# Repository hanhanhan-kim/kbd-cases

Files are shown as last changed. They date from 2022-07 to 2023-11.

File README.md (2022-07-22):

# Keyboard Cases

A collection of keyboard cases I've designed. For each keyboard case, I provide all files for assembly, as well as instructions for setting up the case. Most of my cases target 40% ortholinear keyboards. 

| Case | Mounting Style | Target Keyboard | Photo |
| --- | --- | --- | --- |
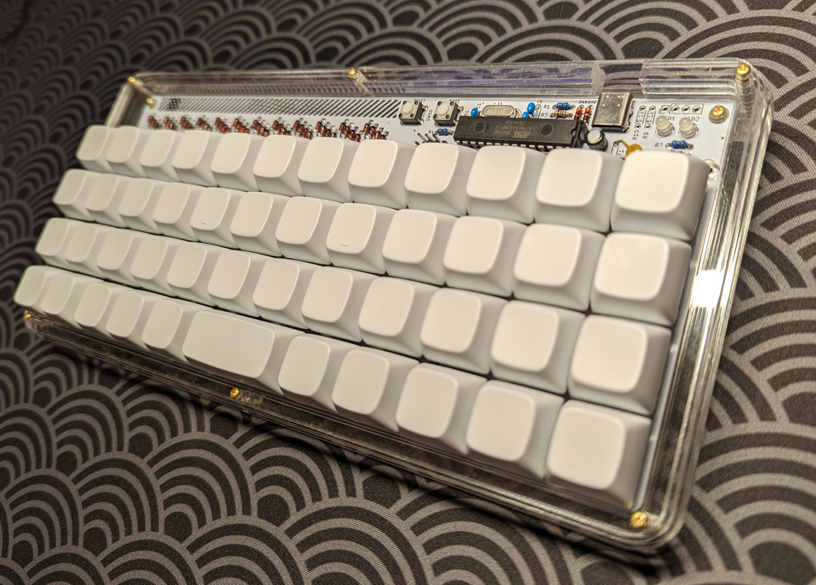
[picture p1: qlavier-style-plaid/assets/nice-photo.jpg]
| [Qlavier](./qlavier-style-plaid) | Silicone o-ring burger mount | [Plaid](https://github.com/hsgw/plaid) |  |
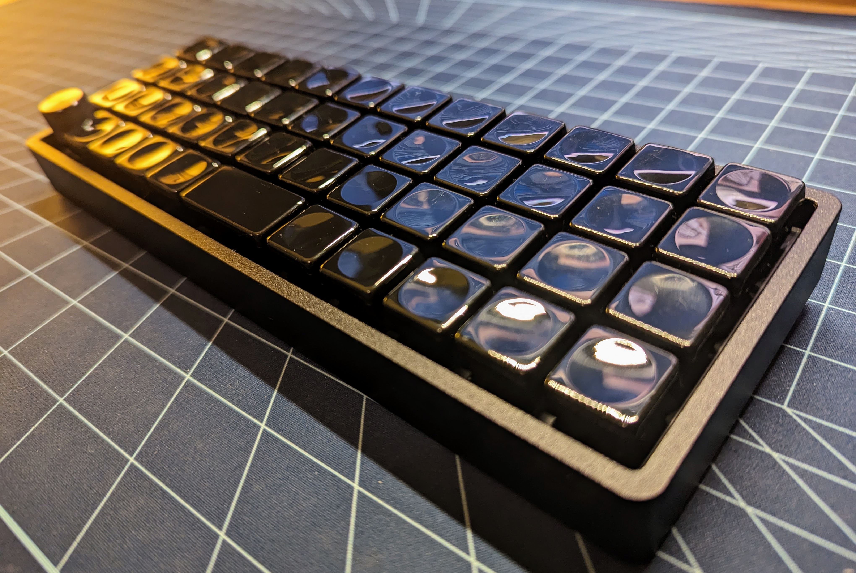
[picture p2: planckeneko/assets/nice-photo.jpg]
| [Planckeneko](./planckeneko) | Gummy o-ring gasket mount | [Planck](https://olkb.com/) |  |

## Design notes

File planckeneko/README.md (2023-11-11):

# Planckeneko

*A gummy o-ring gasket-mounted case for the popular [Planck](https://olkb.com/collections/planck) keyboard. Based on the cleverly designed [Bakeneko 60](https://github.com/kkatano/bakeneko-60).*



This project provides hardware files and assembly instructions for building a CNC-machined brass-weighted gasket-mounted case for the [Planck](https://olkb.com/collections/planck) keyboard. Alternative hardware files are provided for CNC-machining a version of the case without the brass weight, but explicit instructions are not provided (assembly can be figured out from the instructions for the brass-weighted version). This project also provides hardware files for making a 3D-printed version of the case, and again, explicit assembly instructions are not provided, because the assembly can be inferred from the instructions for the brass-weighted version here. 

## BOM

Aside from the CNC-machined (or 3D-printed) parts*, the following items are needed for the case:

| Item | Unit Price (USD) | Quantity | Source |
| --- | --- | --- | --- |
| Soft silicone o-ring, 1/8" fractional width, 70 Duro hardness| 10.18 | 1 | O-Ring Store [B70260](https://www.theoringstore.com/store/index.php?main_page=product_info&cPath=367_23_25&products_id=1275) |
| Unified daughterboard, 4-pin JST cable, four M2 x4 mm screws | 8.00 | 1 | Cannon Keys [UNIFIED-DB](https://cannonkeys.com/products/unified-daughterboard-and-jst-cable) ** |
| M2 x4 mm brass hex drive flat head screw | 7.33 / n | 2 | McMaster [97595A266](https://www.mcmaster.com/97595A266/) |
| Wide furniture bumpers | 6.98 / 4 | 4 | ASIN [B0856T8HJF](https://www.amazon.com/gp/product/B0856T8HJF/ref=ppx_yo_dt_b_search_asin_title?ie=UTF8&psc=1) |

*If 3D-printing, use the files found [here](./3dp). If CNC-machining with no brass bar, use the files found [here](./cnc-plain). If CNC-machining with the weighted brass bar, use the files found [here](./cnc-weighted). 

**The daughterboard is [open-sourced](https://github.com/ai03-2725/Unified-Daughterboard), so it can be manufactured for cheaper, but in multiples, at a PCB fabrication house. 

## Assembly

The [drawing](./assets/drawing.png) gives us a reasonable idea of the case geometry. Note the recesses on the bottom:

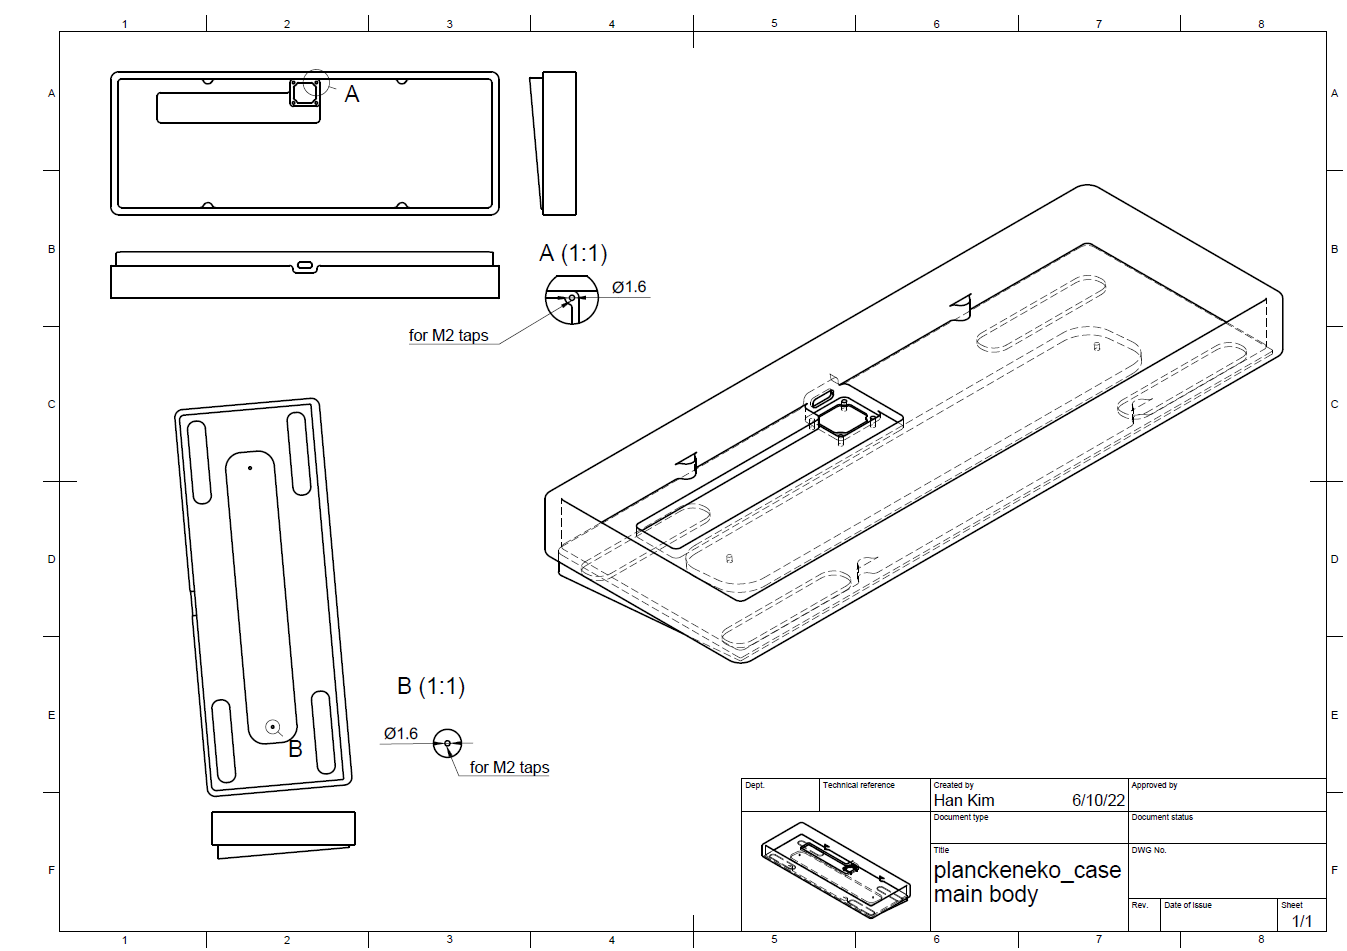
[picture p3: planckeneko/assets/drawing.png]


Lay out the CNC'd parts.



Use the flat head M2 screws to screw the brass bar into the bottom recess of the main case body. Carefully stick on the furniture bumpers into their dedicated recesses. 

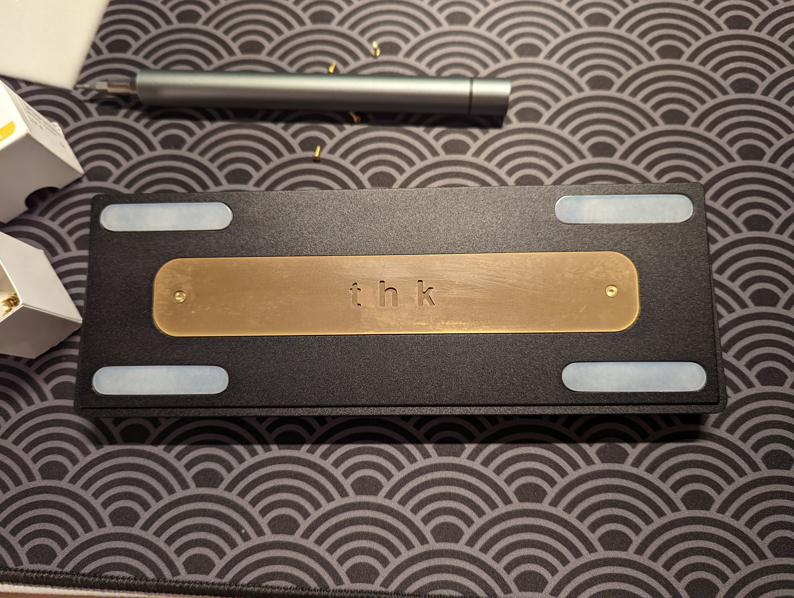
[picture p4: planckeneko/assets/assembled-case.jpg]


We now need to modify the Planck PCB. We need to desolder the original USB-C port off the Planck. Then, we need to cut out the jutted part of the PCB that supported the original USB-C port. I found that a pair of flush-cutters did the trick just fine. The image below marks in red what the PCB looks like after the protrusion's been cut:

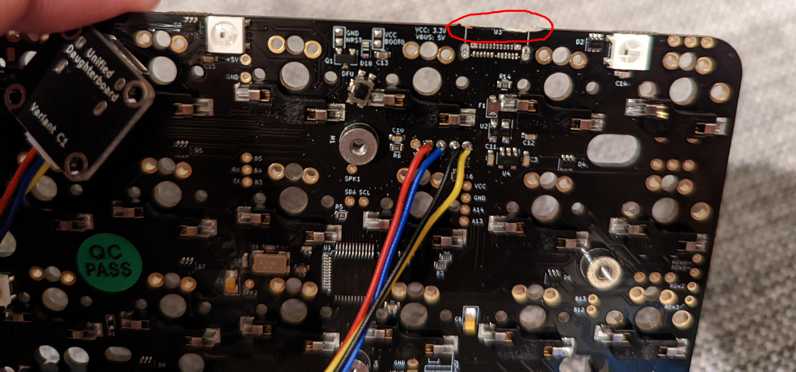
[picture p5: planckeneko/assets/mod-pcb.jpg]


Notice that the above image also has some red, blue, black, and yellow wires soldered in. These wires are the JST cable wires that go into the USB-C daughterboard. The Planck PCB has a neat feature, where we can bypass the original USB port, and install our own upstream. This feature is handy in the case of defective USB ports, but it's also handy because it lets us install a daughterboard, which is expected of mostf gasket-mounted keyboards.  Unfortunately, the daughterboard JST wires that come from Cannon Keys are not the standard colours for USB 2.0, so we should look at the [daughterboard's datasheet](https://github.com/ai03-2725/Unified-Daughterboard/wiki/PCB-side-design-resources) (doing so is always good practice, anyway). Here, we can see the USB pinout for the daughterboard:

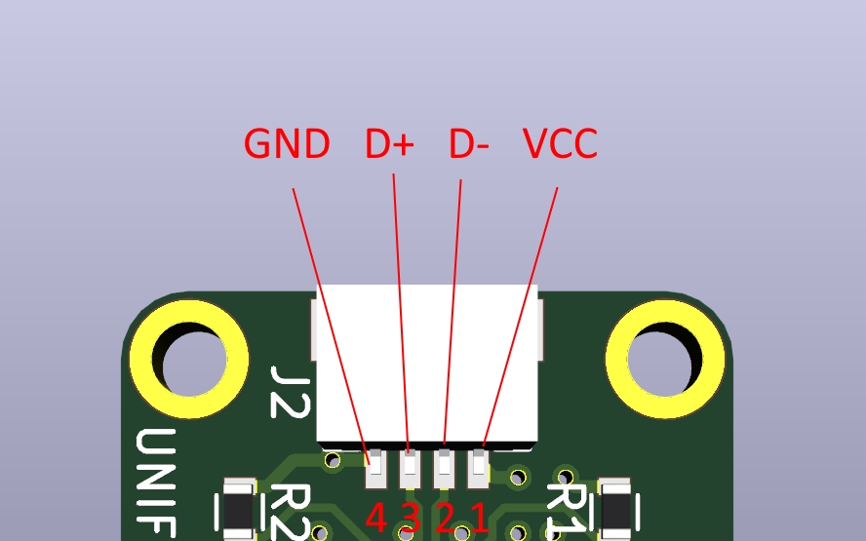
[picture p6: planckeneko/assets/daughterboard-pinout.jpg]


Similarly, we can see the USB pinout silkscreened on the breakout holes of the Planck PCB:

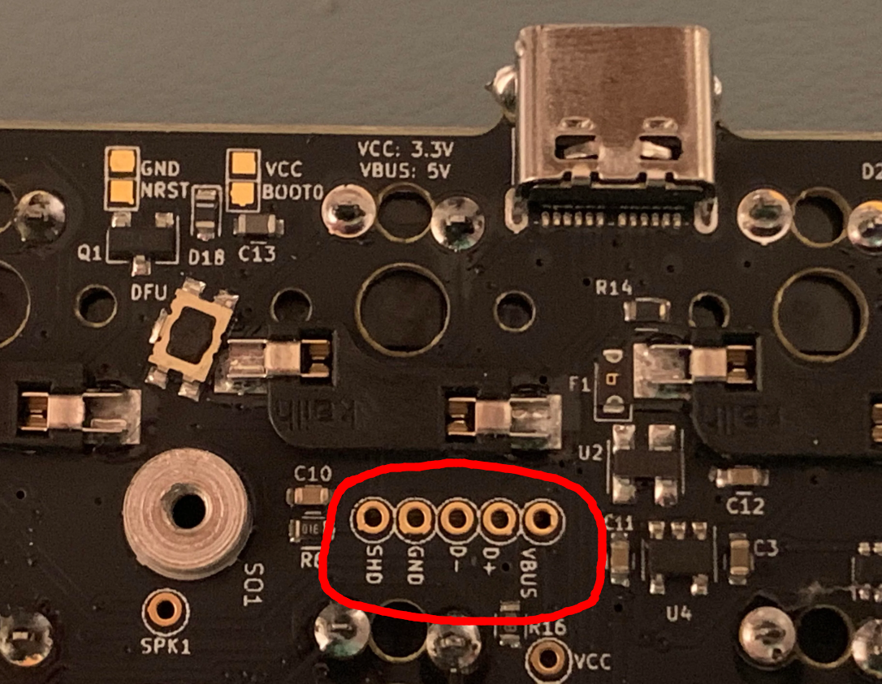
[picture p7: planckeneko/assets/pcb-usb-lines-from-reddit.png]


We can ignore the SHD pin, and connect the USB pins on the Planck PCB to the corresponding USB daughterboard PCB pins. The Planck PCB clearly doesn't have a JST connector though, so we're going to cut off the JST connector on one end of the cable, and solder the wires directly to the Planck (as shown a few images above, with the red, blue, black, and yellow wires). The daughterboard has JST connectors though, so we can just click those in place. Remember to solder the JST wires to the _bottom_ side of the Planck PCB. Once all the electrical connections are complete, screw the daughterboard into the case. We should now have something that looks like this:

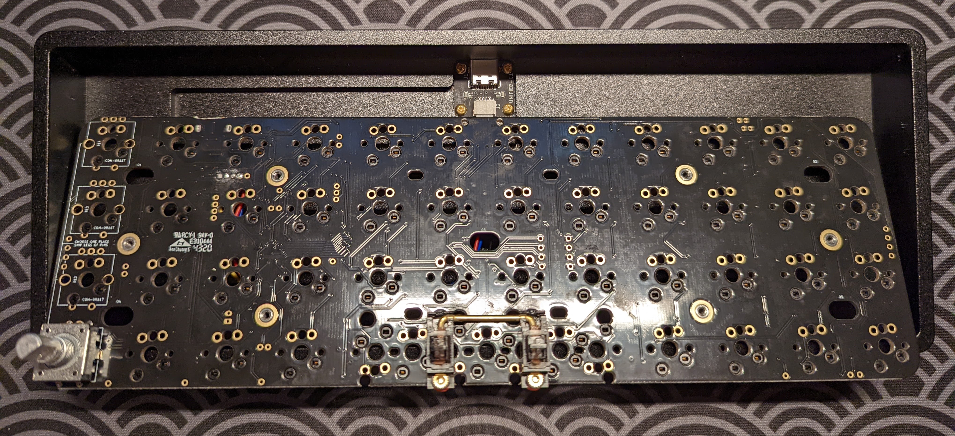
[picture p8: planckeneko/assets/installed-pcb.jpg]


We now install the switches and switch plate, just like a normal keyboard build. Then, we wrap the o-ring around the entire PCB / switch plate, such that the o-ring sits happily between PCB and the switch plate. Set this construction into the keyboard case, with the south side facing first. The o-ring on the south side of the PCB construction should sit nicely on the semi-circular columns found on the inside edge of the case.

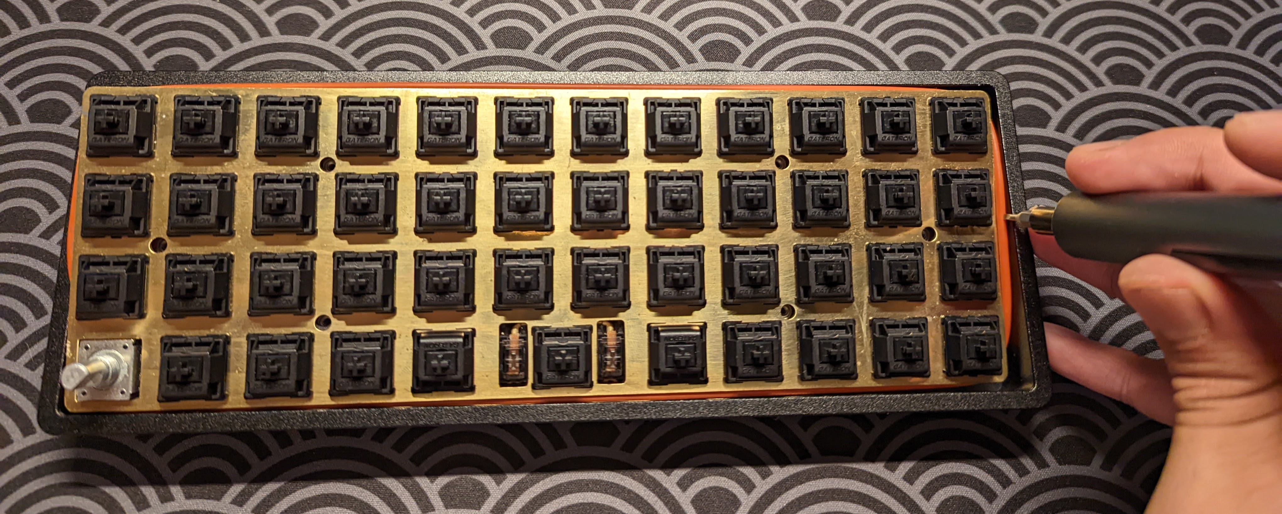
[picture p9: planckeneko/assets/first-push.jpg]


Use a flathead screwdriver to push down the o-ring and the PCB assembly, all around the assembly's edges. Eventually, the o-ring should be reasonably hidden (but admittedly, not completely, depending on your view angle). The o-ring I've since opted for using is black (from the O-Ring Store) rather than black (from McMaster-Carr). 

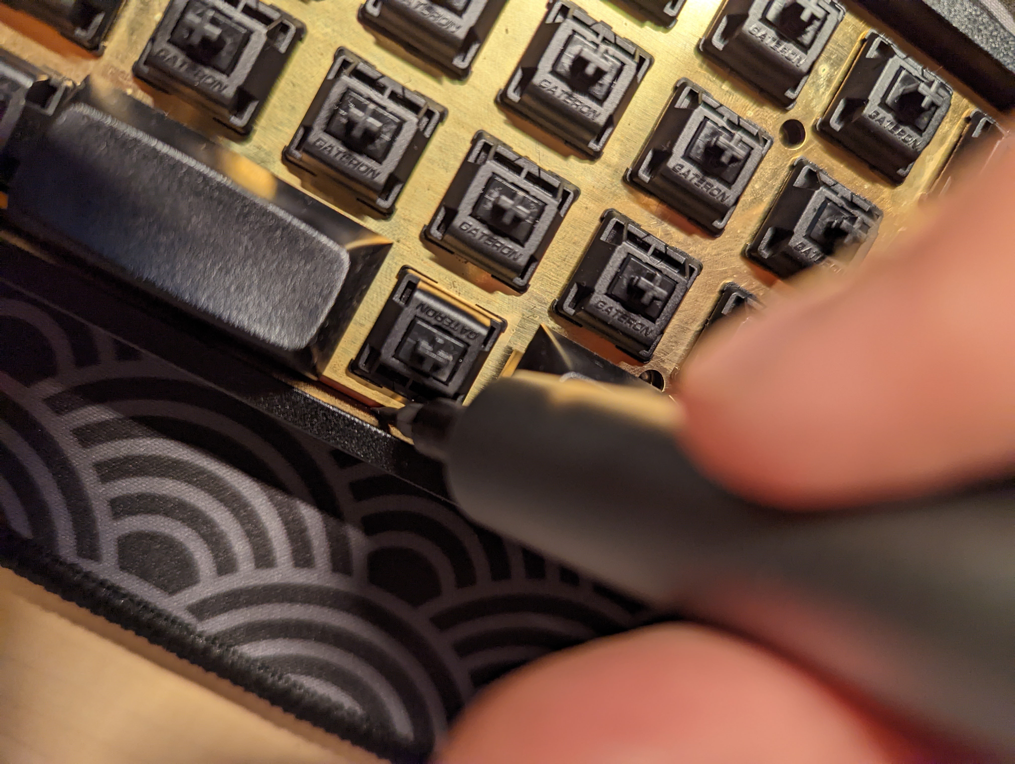
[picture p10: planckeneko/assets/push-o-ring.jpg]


That's it! Enjoy your newfound soft typing feel, and the improved acoustics. 

## Future Improvements

Honestly, I'm pretty happy with the build. If I had to change one thing, I'd probably make the edges of the keyboard a little taller, so that they hide the switches---but that's just a minor aesthetic preference.

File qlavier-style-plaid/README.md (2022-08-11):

# Qlavier-Style Case for the Plaid Keyboard

*A silicone burger-mounted stacked acrylic case for the [Plaid](https://github.com/hsgw/plaid) keyboard, reverse engineered from [Qlavier](https://qlavier.com)'s [image gallery](https://imgur.com/a/e2AHRcN).*



This project provides hardware files and assembly instructions for building a stacked acrylic case for the [Plaid](https://github.com/hsgw/plaid) keyboard. It's a reverse engineering of [Qlavier](https://www.qlavier.com/)'s case design for the keyboard. 

## BOM

Aside from the M2 x8mm screws and the 1/8" thick acrylic, one of the linked M2 standoff screw kits is all you need. In general, aside from the small silicone o-rings, the parts listed here are very standard and easy to source. 

| Item | Unit Price (USD) | Quantity | Source |
| --- | --- | --- | --- |
| M2 x20 mm (F-F) hex standoffs<br />3 mm from hexagon edge to opposite edge | 13.99 / n | 3 | ASIN [B07PDQ7DVS](https://www.amazon.com/gp/product/B07PDQ7DVS/ref=ppx_yo_dt_b_search_asin_title?ie=UTF8&th=1) |
| M2 x10 mm, but preferably M2x12 mm, (F-F) hex standoffs<br />3 mm from hexagon edge to opposite edge | 13.99 / n | 3 | ASIN [B07PDQ7DVS](https://www.amazon.com/gp/product/B07PDQ7DVS/ref=ppx_yo_dt_b_search_asin_title?ie=UTF8&th=1) |
| M2 x5mm screws | 13.99 / n | 14 | ASIN [B07PDQ7DVS](https://www.amazon.com/gp/product/B07PDQ7DVS/ref=ppx_yo_dt_b_search_asin_title?ie=UTF8&th=1) |
| M2 nuts | 13.99 / n | 2 | ASIN [B07PDQ7DVS](https://www.amazon.com/gp/product/B07PDQ7DVS/ref=ppx_yo_dt_b_search_asin_title?ie=UTF8&th=1) |
| M2 x8 mm screws | 12.04 / 50 | 2 | McMaster [92942A801](https://www.mcmaster.com/92942A801/) |
| 1/8" thick acrylic | ~ | ~ | ~ |
| Silicone o-rings, 4 mm OD, 1 mm ID, 1.5 mm ring width | 5.49 / n | 2 | ASIN [B082SVFWCS](https://www.amazon.com/gp/product/B082SVFWCS/ref=ppx_yo_dt_b_search_asin_title?ie=UTF8&th=1) |

## Assembly

We want to try and assemble something that looks like this render:

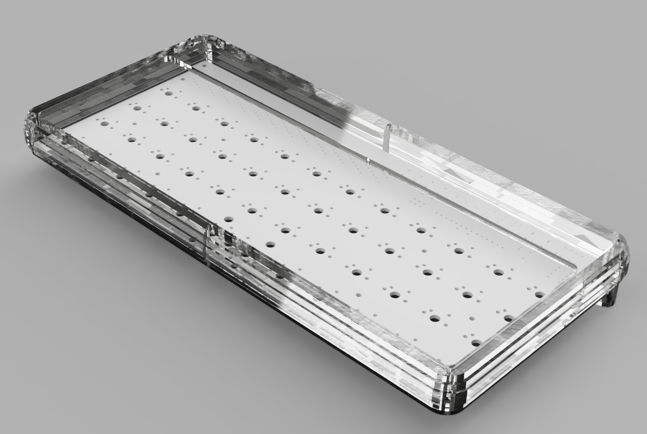
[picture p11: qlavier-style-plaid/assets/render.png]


It's hard to see the footbar from the render, but we want to order the acrylic such that the narrower feet are on the bottom, and the wider feet are on the top. We use three screws and three F-F hex standoffs to secure the feet together, from the bottom. 

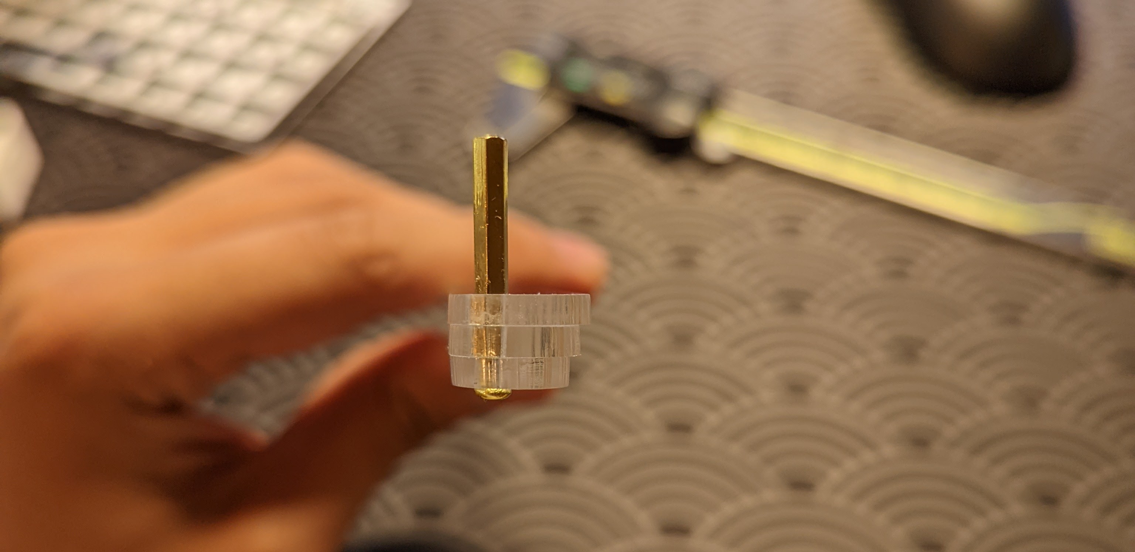
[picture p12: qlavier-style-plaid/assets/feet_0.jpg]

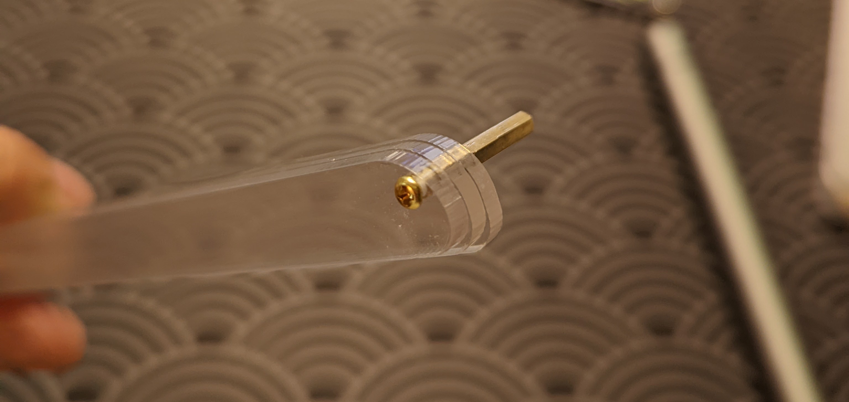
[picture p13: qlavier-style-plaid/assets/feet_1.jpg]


We then stack on the layers that will hold the actual case. We want to order the layers such that it gets wider in the middle, and narrower at the ends. Make sure to position the USB cutout to the right side, so that it matches up with the Plaid's USB port. Do not yet put on the very top layer that would cover the exposed PCB components. 

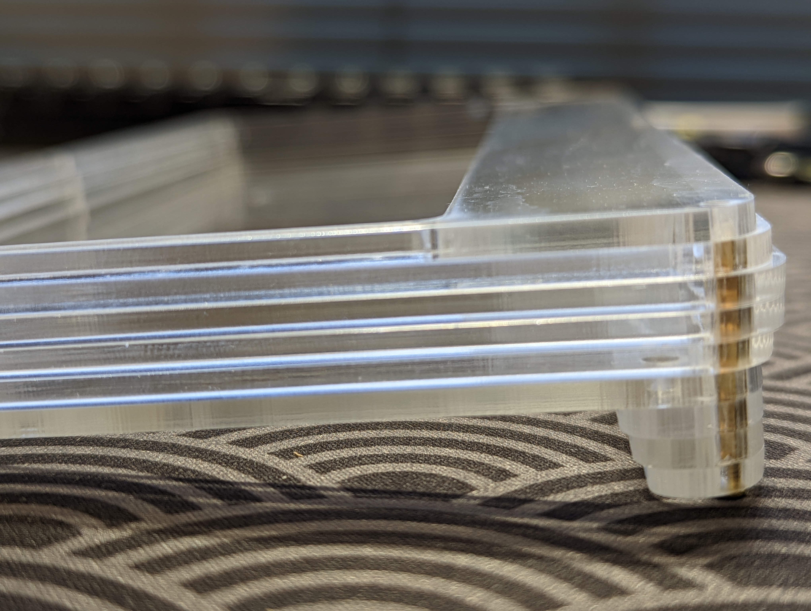
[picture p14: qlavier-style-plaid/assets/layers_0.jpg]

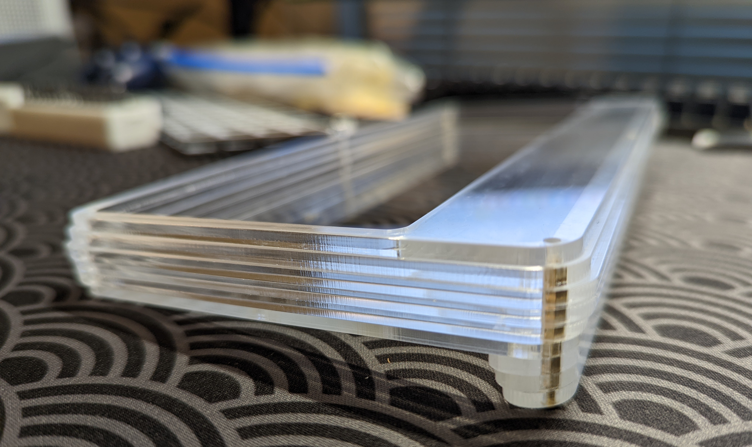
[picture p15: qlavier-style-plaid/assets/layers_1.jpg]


We now need to prepare the PCB. Install the stabilizers first, like with any keyboard build. Then, install the screws. 

For the north-most two mounting holes, slip the silicone o-rings on the screws such that there's an o-ring above the PCB, and an o-ring beneath the PCB. Very little of the screw threads should be sticking past the bottom o-rings. Despite what the following photo shows, _do not yet install the switches and switch plate_. 

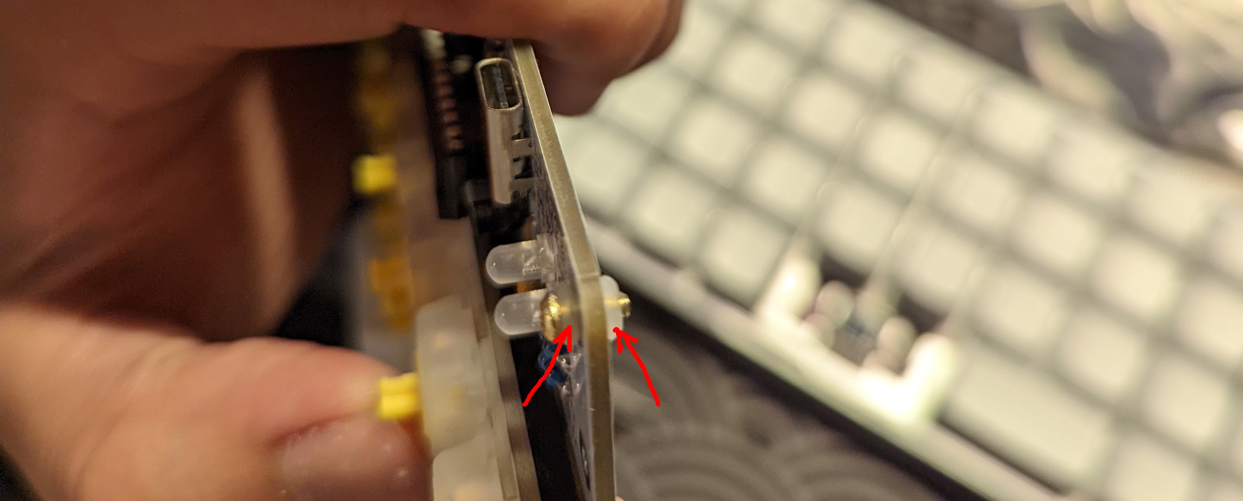
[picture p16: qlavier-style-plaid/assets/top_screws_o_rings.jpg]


We're going to use the longer M2 x8 mm screws for the south-most mounting holes on the PCB. We're going to slip on the silicone o-rings onto the screw threads from _only the bottom side of the PCB_, for these two screws. So each bottom screw has one less o-ring than its top-screw counterpart. 

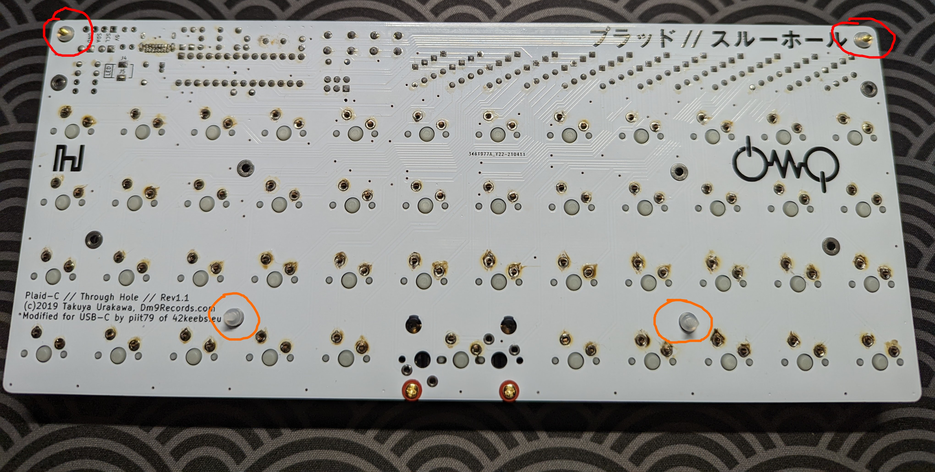
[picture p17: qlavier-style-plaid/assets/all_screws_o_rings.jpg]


Now install the switches and switch plate, like you would for any keyboard build. Finally, put on the top plate. The top plate is obvious, because it will cover the PCB's top through-hole components, and its holes are circular clearance holes for M2 screws, as opposed to hexagonal cut-outs for the standoffs. _Be extremely careful when handling the top layer._ The south side of the top layer is really delicate, and can break easily, until it's screwed in to the rest of the case. 

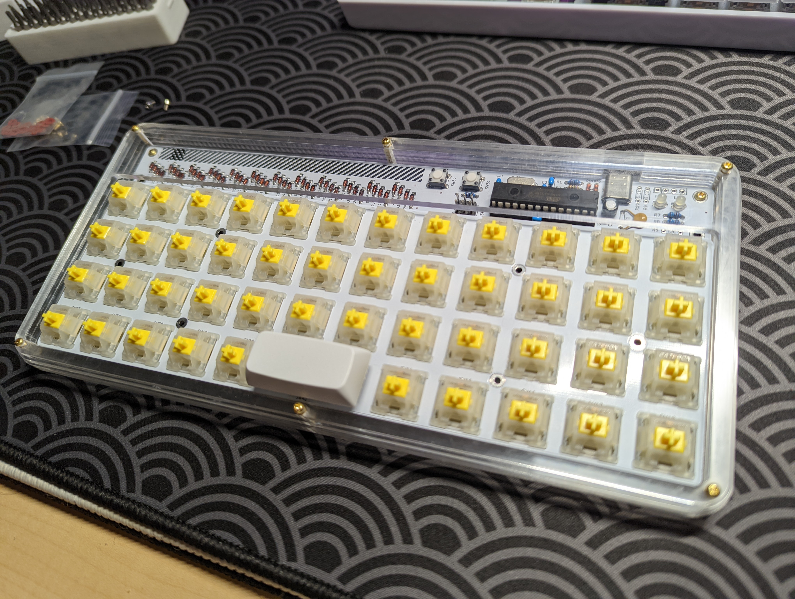
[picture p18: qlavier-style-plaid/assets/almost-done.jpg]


Finally, we're going to flip the keyboard upside-down. Find the exposed threads of the south-most PCB-mounting screws, and screw on the M2 nuts. If not enough of the threads are exposed, push the top part of the screw with something like a very skinny hex wrench, while screwing in the nut. 

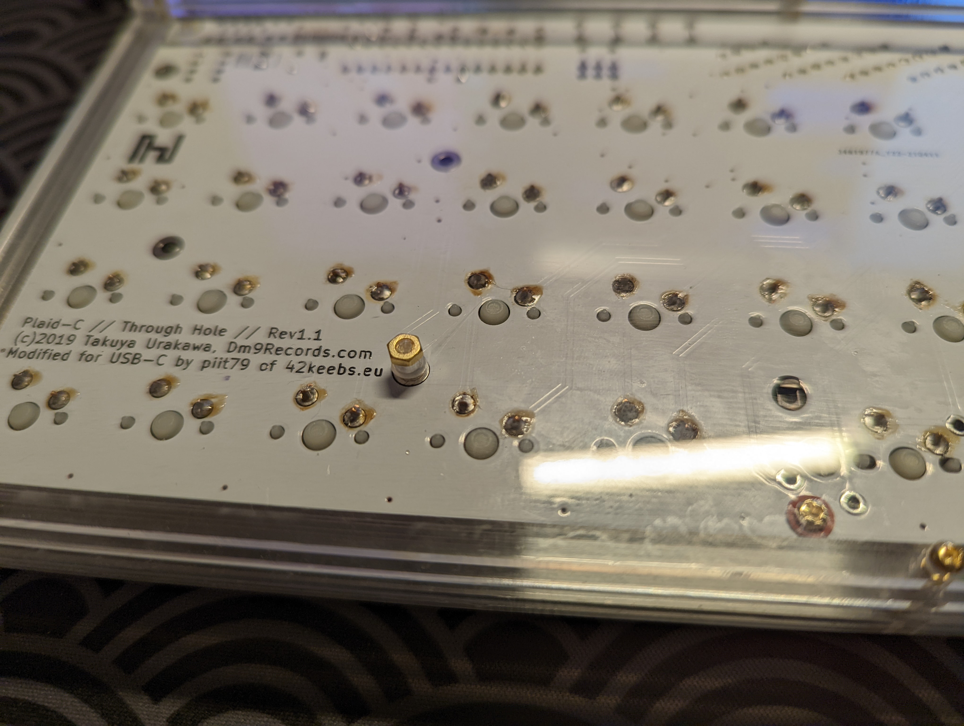
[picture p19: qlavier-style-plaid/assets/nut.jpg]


Tada! :tada: We're done! Enjoy the keyboard! 

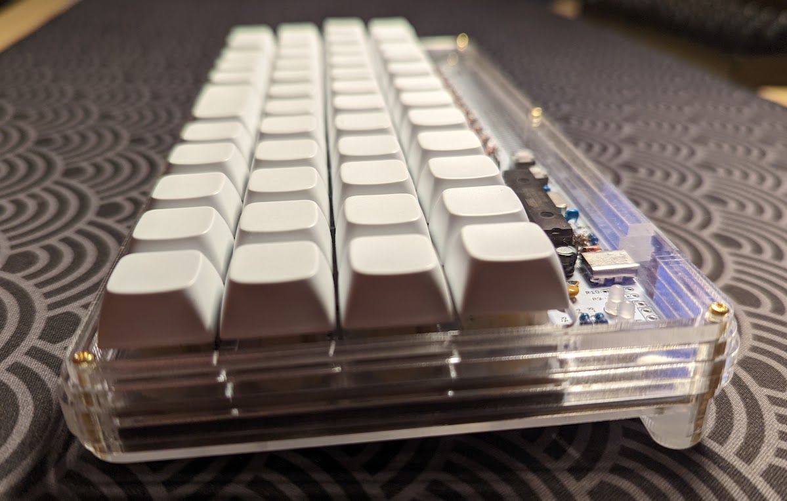
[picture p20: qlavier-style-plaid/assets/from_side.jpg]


## Future Improvements

I think I'd make the following improvements, if I had to do this build again:

- The clearance on the USB cutout from the left side (when the keyboard is viewed from the top) is a little too tight. I'd cut it out more to the left. 
- The top layer is way too delicate. It's because I just carved out the interior of the top layer last minute, to give enough clearance for the keycaps. Ideally, I'd move the screw holes on all the layers closer to the outside edge, and (or) I'd give the keyboard more of a bezel. 
- I should make cutouts for the boot and reset buttons.

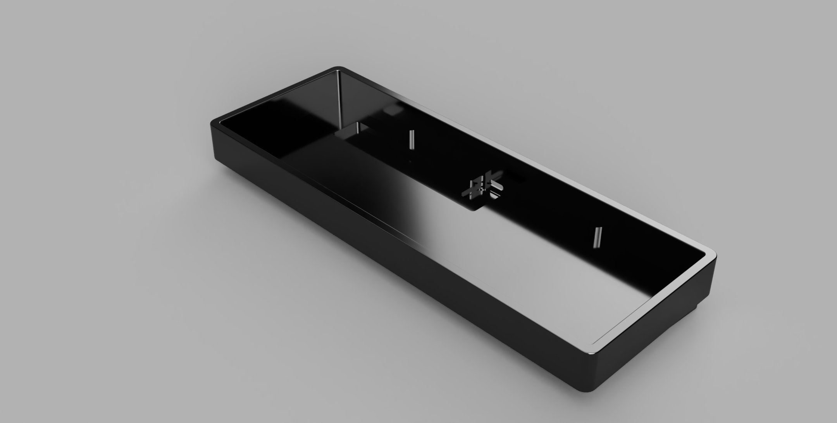
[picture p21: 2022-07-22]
planckeneko/assets/render-top.png

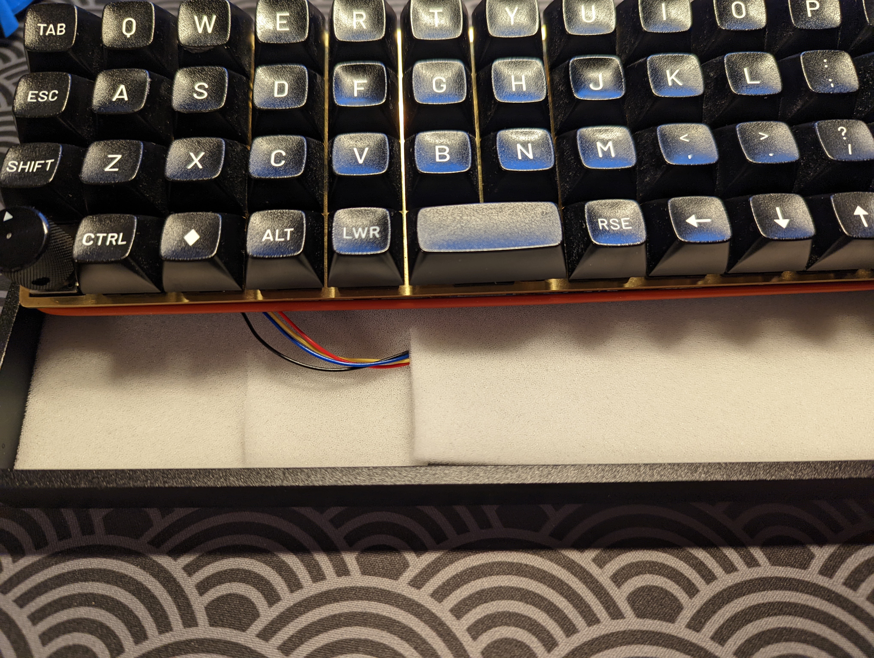
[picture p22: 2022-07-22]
planckeneko/assets/foam-cut.jpg

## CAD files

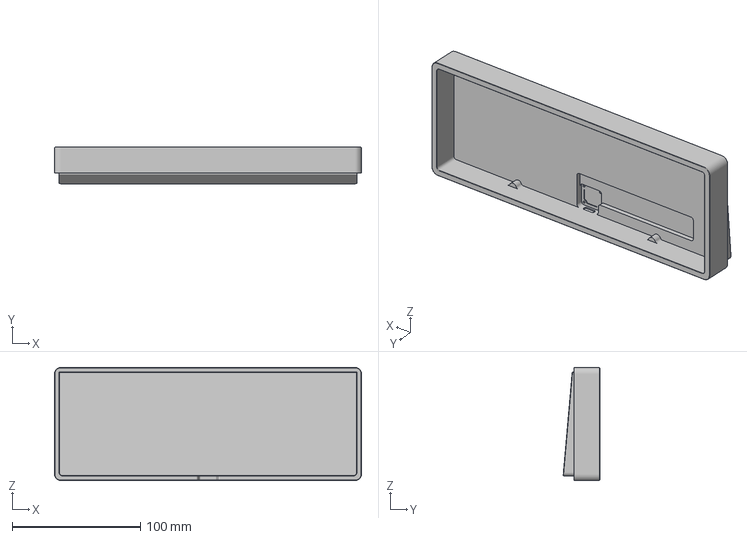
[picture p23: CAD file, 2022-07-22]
planckeneko/3dp/main.3mf
239.0 x 28.5 x 88.0 mm

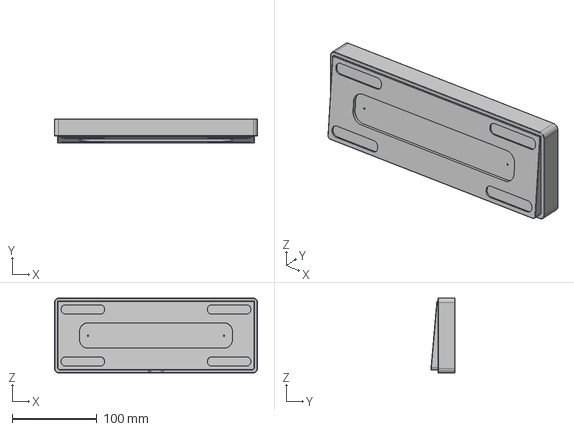
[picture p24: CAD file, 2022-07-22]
planckeneko/cnc-weighted/main.step
239.0 x 28.5 x 88.0 mm

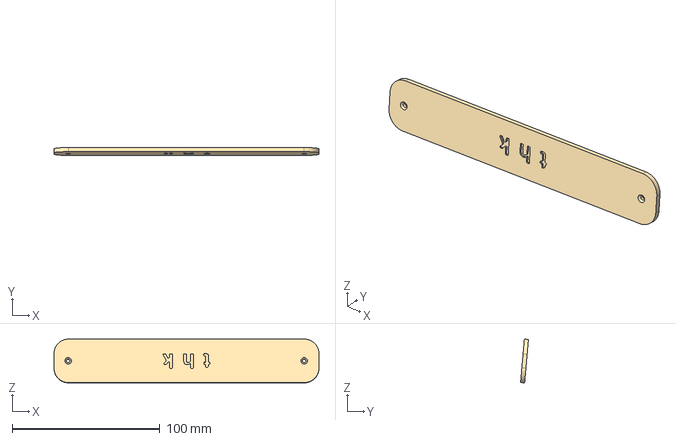
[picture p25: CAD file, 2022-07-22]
planckeneko/cnc-weighted/brass_weight.step
179.6 x 5.37 x 29.7 mm

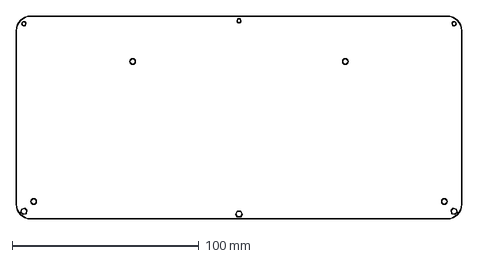
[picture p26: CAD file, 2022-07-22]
qlavier-style-plaid/lasercut-files/layer_6.dxf
238.6 x 108.6 mm

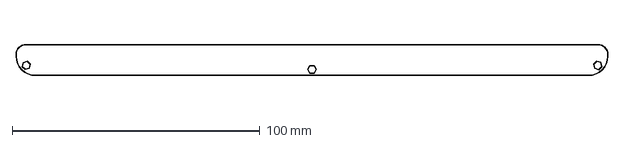
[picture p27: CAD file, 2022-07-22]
qlavier-style-plaid/lasercut-files/layer_-2.dxf
238.6 x 12.5 mm

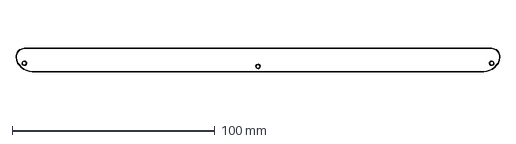
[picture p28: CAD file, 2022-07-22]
qlavier-style-plaid/lasercut-files/layer_-3.dxf
238.8 x 11.4 mm

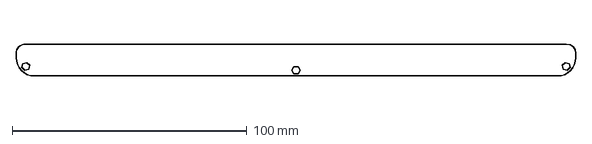
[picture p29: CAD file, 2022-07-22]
qlavier-style-plaid/lasercut-files/layer_-1.dxf
238.6 x 13.6 mm

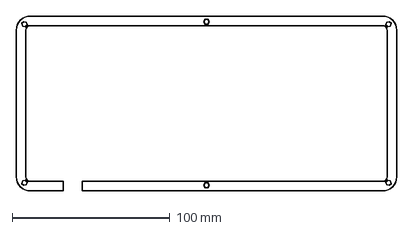
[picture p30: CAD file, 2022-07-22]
qlavier-style-plaid/lasercut-files/layer_5.dxf
240.8 x 110.8 mm

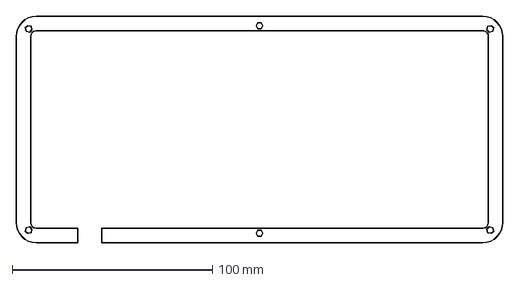
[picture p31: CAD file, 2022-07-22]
qlavier-style-plaid/lasercut-files/layer_4.dxf
243.0 x 113.0 mm

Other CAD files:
planckeneko/cnc-plain/main.step
qlavier-style-plaid/lasercut-files/layer_1.dxf
qlavier-style-plaid/lasercut-files/layer_2.dxf
qlavier-style-plaid/lasercut-files/layer_3.dxf

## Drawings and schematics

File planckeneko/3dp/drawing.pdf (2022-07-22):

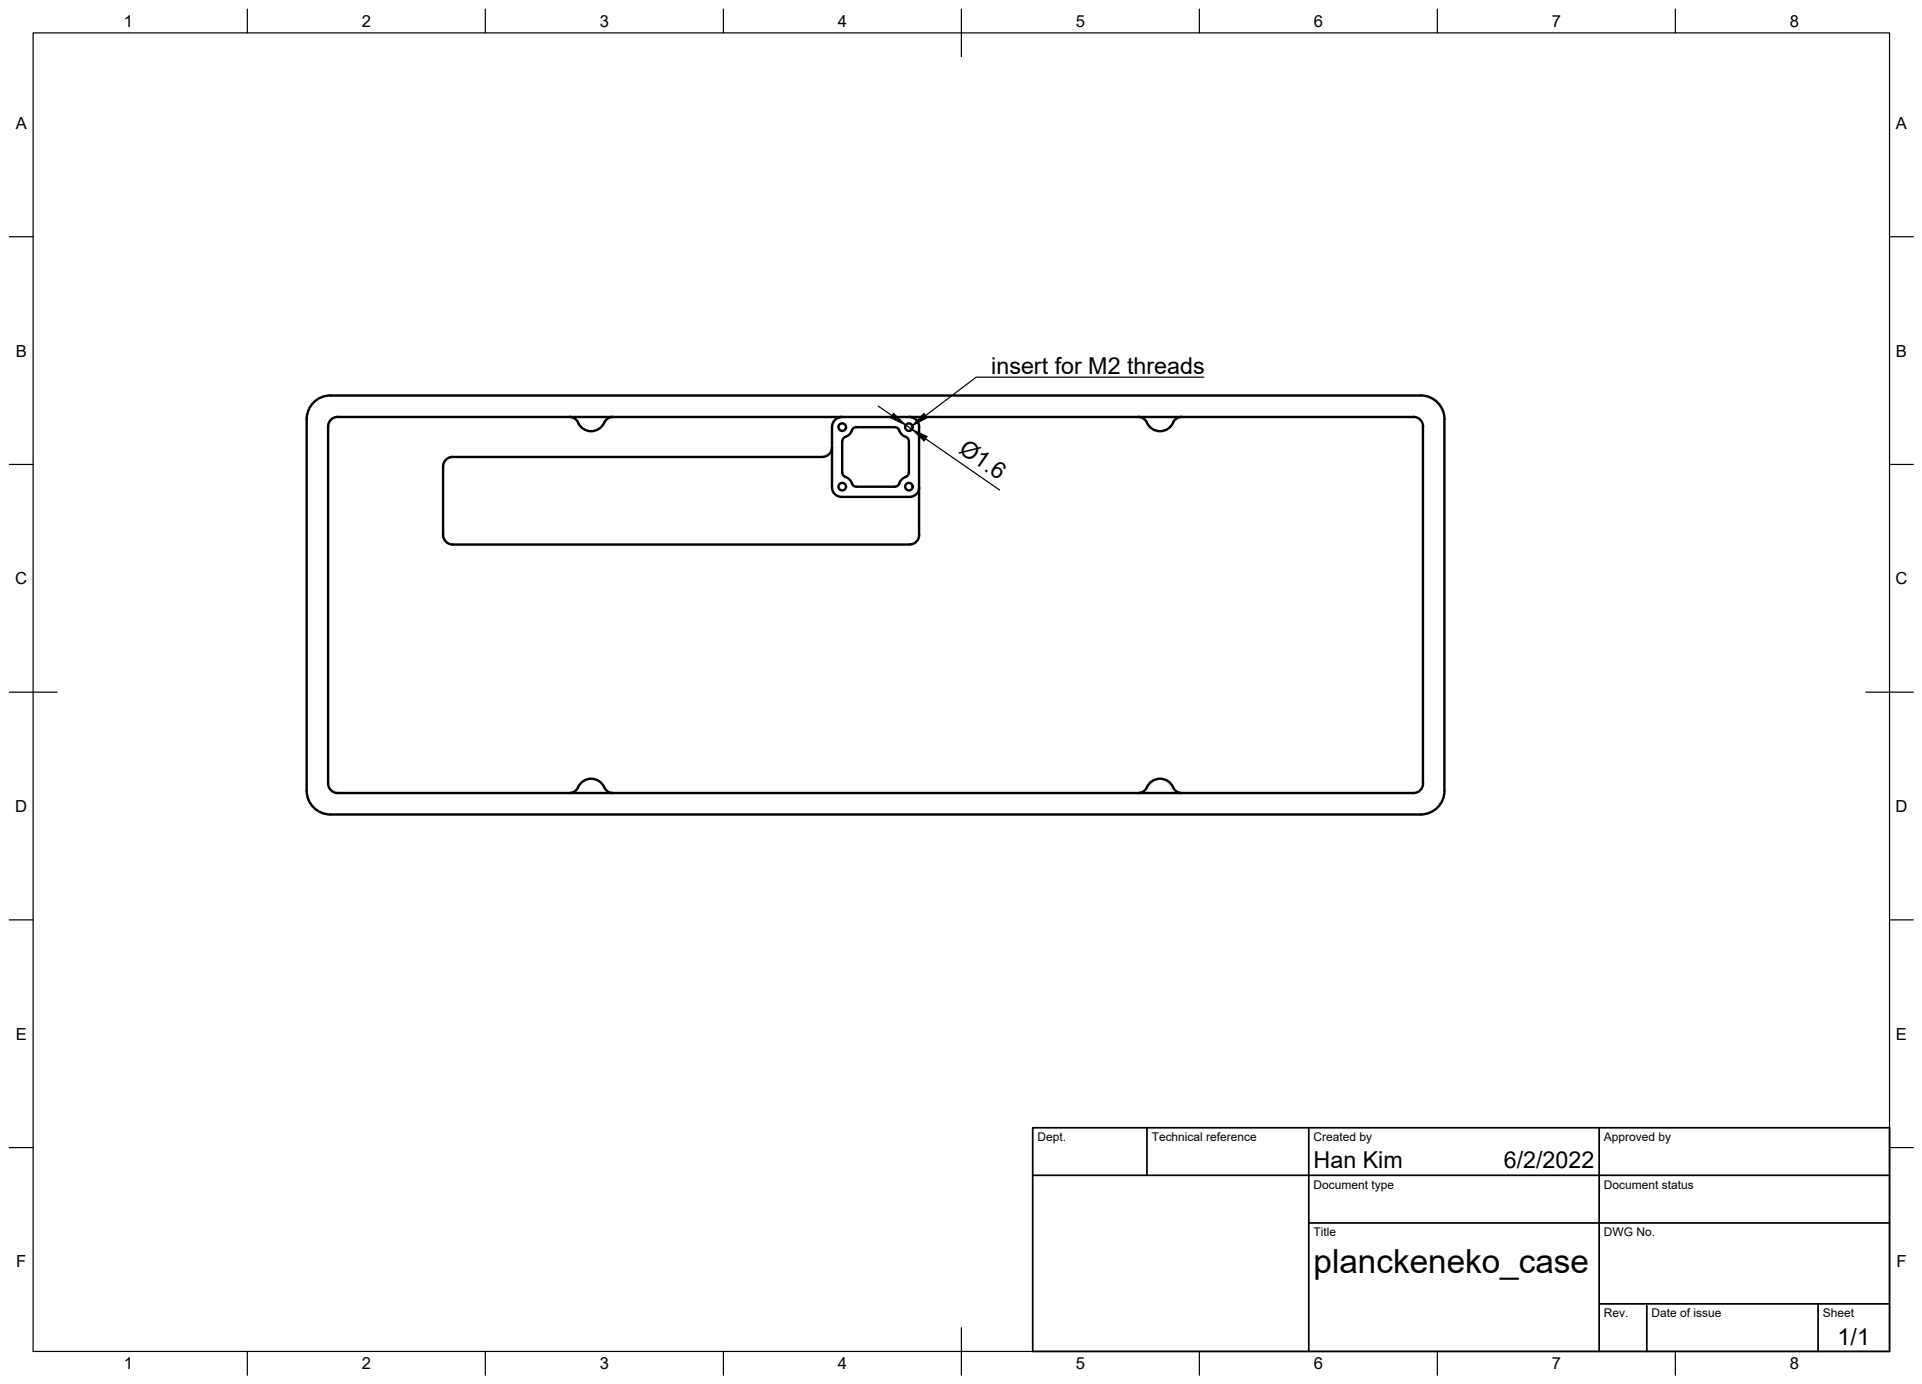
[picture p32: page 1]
Title; DWG No.; Rev.; Date of issue; Sheet

insert for M2 threads

Dept. | Technical reference | Created by Han Kim 6/2/2022 | Approved by

Document type | Document status

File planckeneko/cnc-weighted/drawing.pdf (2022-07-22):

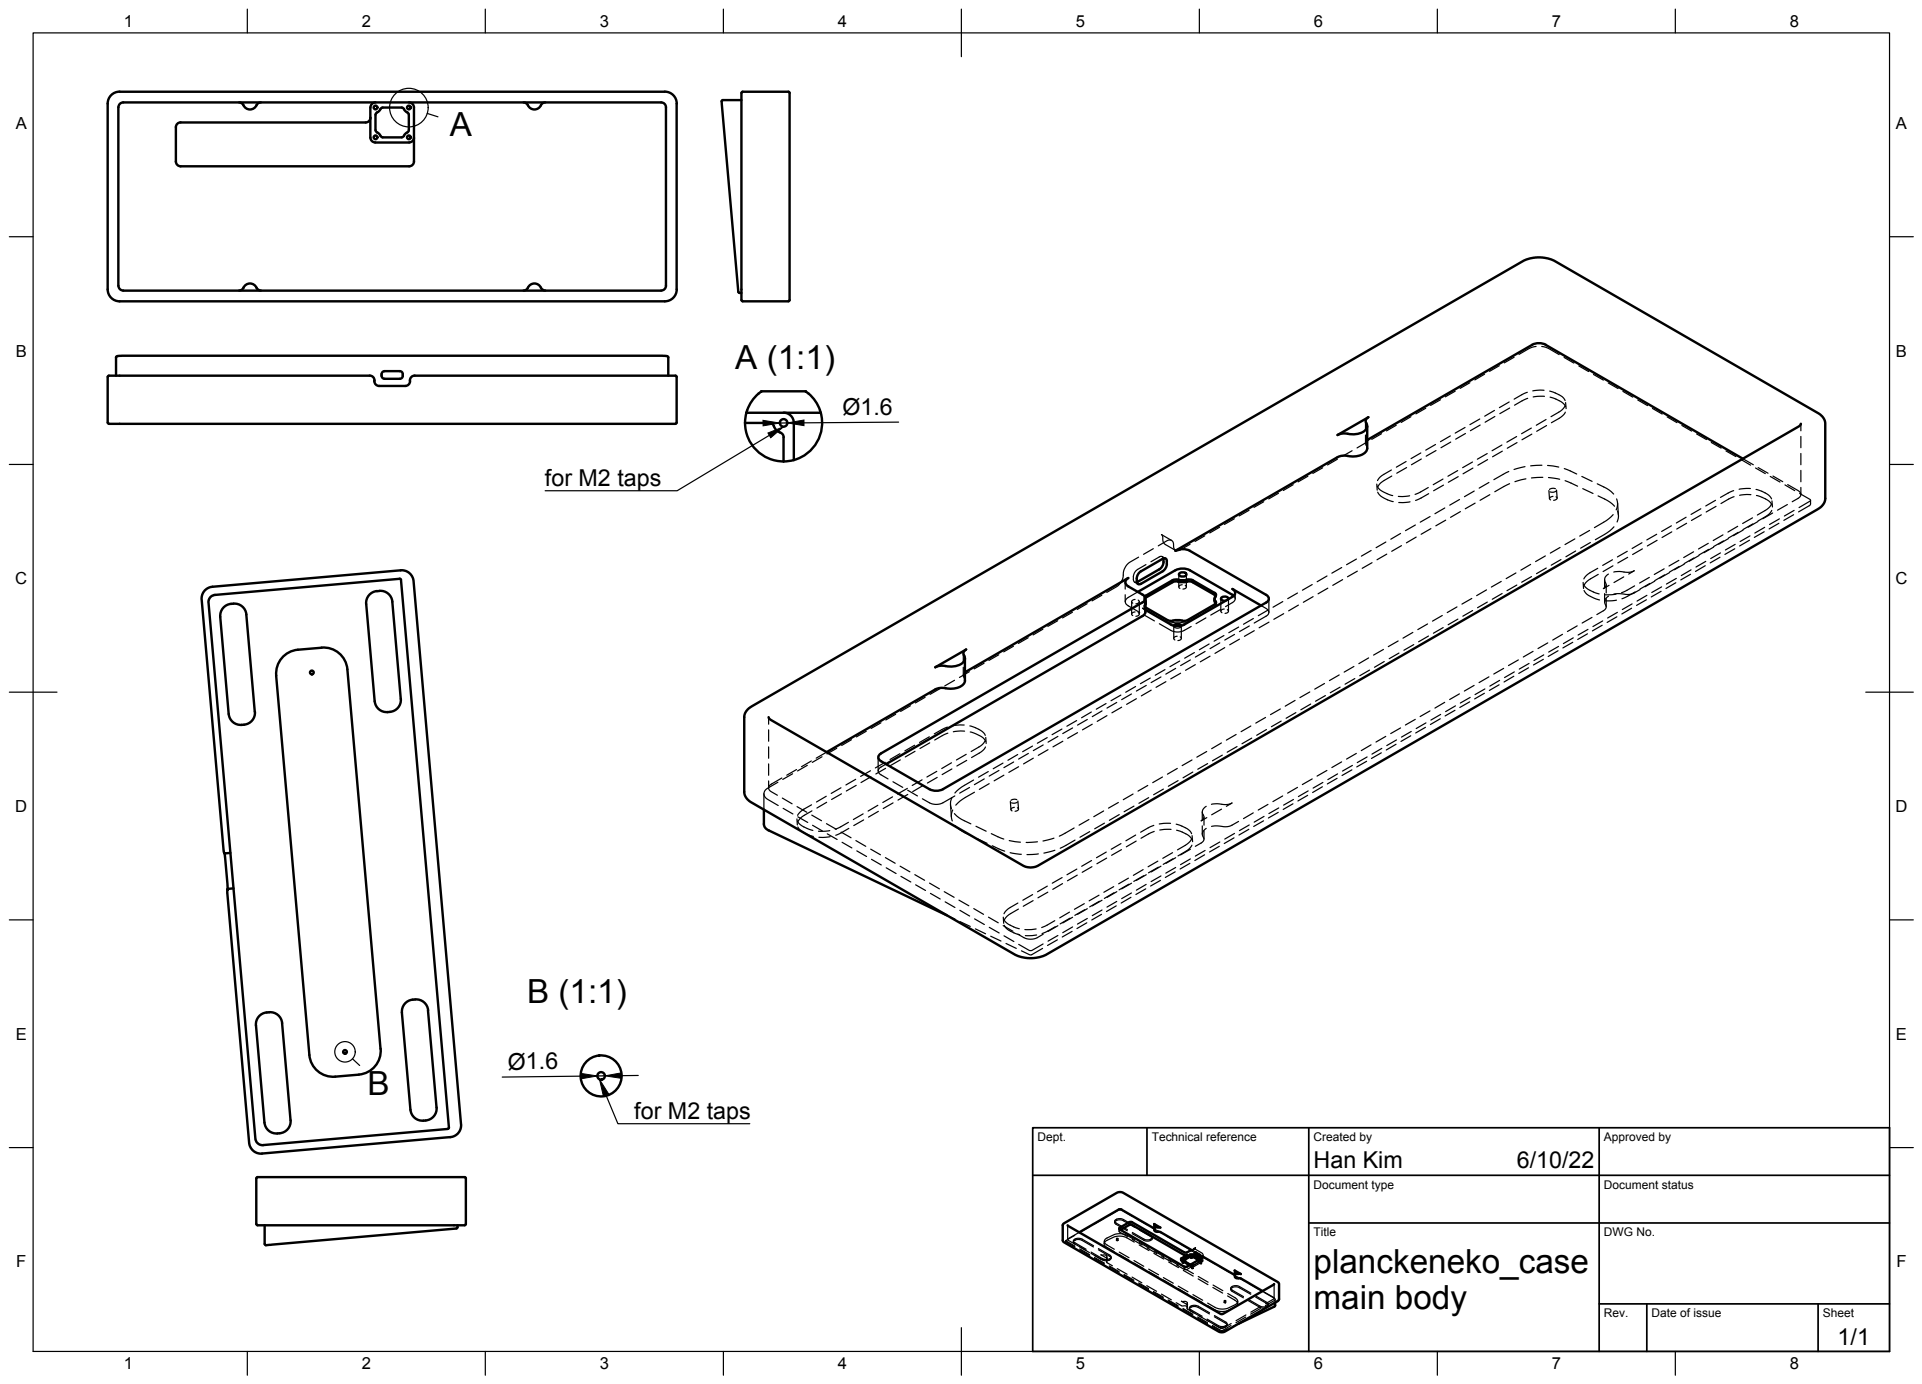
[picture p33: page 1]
Title; DWG No.; Rev.; Date of issue; Sheet; main body; for M2 taps

Dept. | Technical reference | Created by Han Kim 6/10/22 | Approved by

Document type | Document status

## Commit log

2022-07-22 add main readme and some planckeneko stuff
    [planckeneko_case_brass_weight.step, planckeneko_case_main_cnc.step]
2022-07-22 add instructions for planckeneko
    [brass_weight.step, main.3mf, main.step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]
